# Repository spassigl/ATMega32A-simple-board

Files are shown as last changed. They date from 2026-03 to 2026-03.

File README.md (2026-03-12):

# ATMega32A demo board
An ATMega32A demo board with exposed GPIO pins, LEDs, tactile switches and a buzzer

## The project
This is a simple ATMega32A board that I used to test some ideas for a bigger project. 
It's a small factor pcb - 84x44mm - with the following features:
- ATMega32A clocked at 16MHz
- USB-C conneector for power and, with a booloader like urboot, for firmware updates and serial communication. 
- ISP 6-pin connector to flash bootloader or firmware (in case you don't want to use a booloader like urboot or optiboot)
- Power OR-ing - can have both ISP and USB connected
- All the unused GPIO pins are exposed via connectors on the side of the board
- Includes a buzzer, two LEDs, two tactile buttons
- Footprints are optimized for JLCPCB and "Basic" or "Preferred Extended" parts, to lower assembly costs

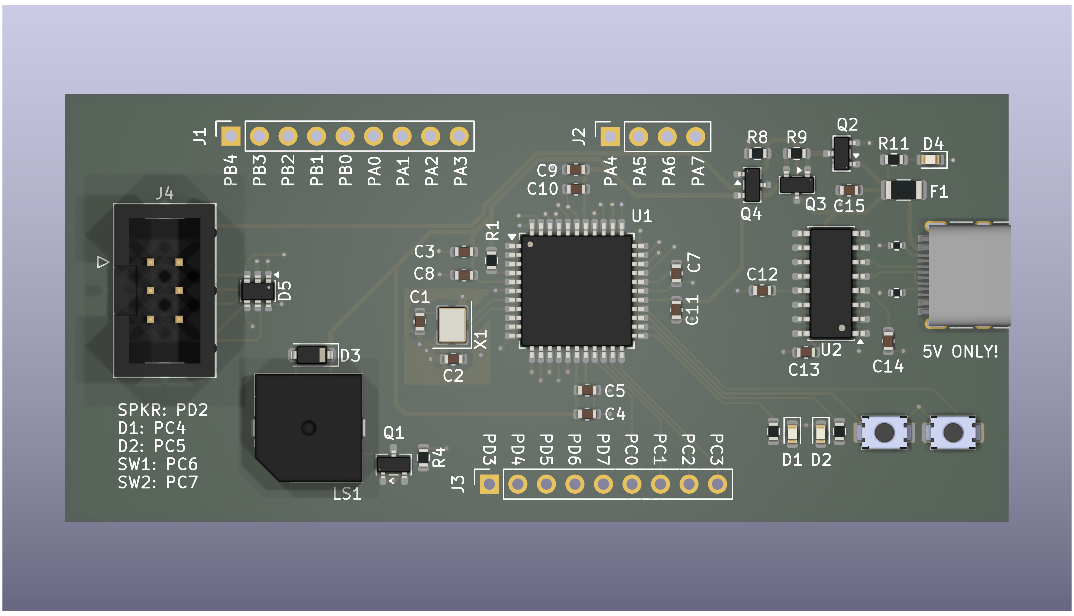
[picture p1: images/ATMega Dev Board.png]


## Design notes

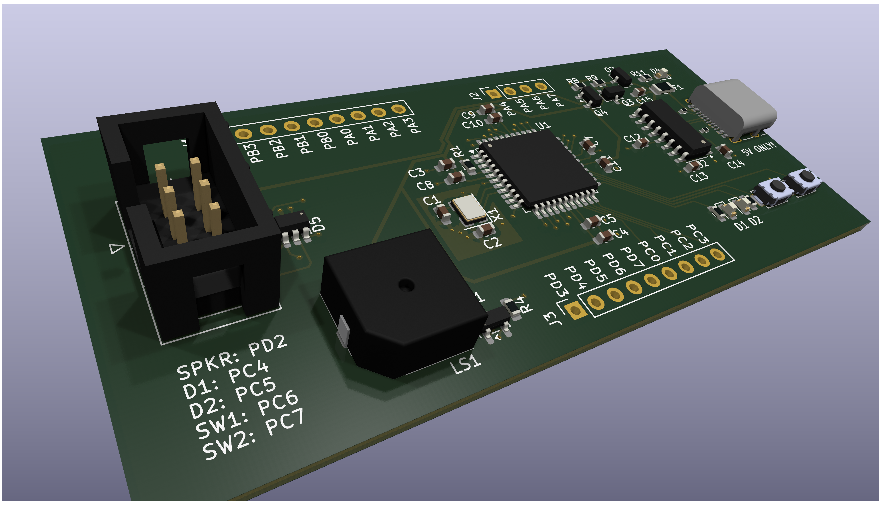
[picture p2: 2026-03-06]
images/ATMega Dev Board 3.png

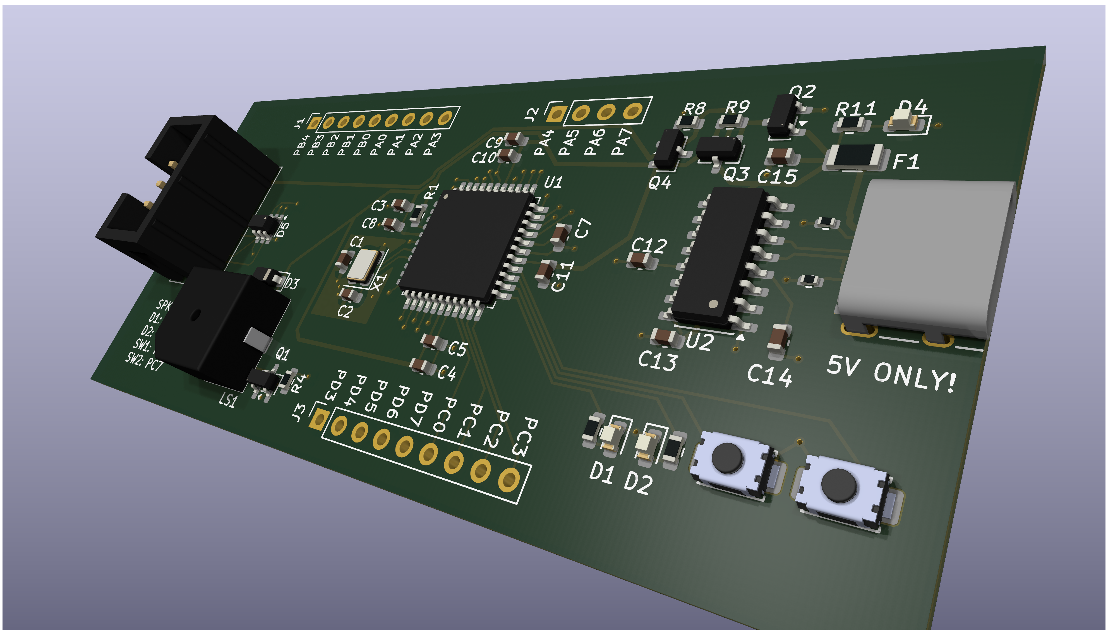
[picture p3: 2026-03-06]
images/ATMega Dev Board 2.png

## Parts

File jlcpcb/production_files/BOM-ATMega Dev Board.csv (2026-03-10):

Comment | Designator | Footprint | LCSC | Quantity
0.1u | C10,C11,C12,C13,C14,C5,C7,C8 | C_0603_1608Metric | C14663 | 8
10k | R1 | R_0603_1608Metric | C25804 | 1
16MHz | X1 | Crystal_SMD_3225-4Pin_3.2x2.5mm | C13738 | 1
1N4001 | D3 | D_SOD-123 | C7462829 | 1
1k | R4 | R_0603_1608Metric | C21190 | 1
1u | C15 | C_0603_1608Metric | C15849 | 1
220 | R11,R2,R3 | R_0603_1608Metric | C22962 | 3
22p | C1,C2 | C_0603_1608Metric | C1653 | 2
2N7002 | Q2 | SOT-23 | C8545 | 1
330k | R8,R9 | R_0603_1608Metric | C23137 | 2
4.7u | C3,C4,C9 | C_0603_1608Metric | C19666 | 3
500mA/24V | F1 | Fuse_1206_3216Metric | C70077 | 1
5k1 | R5,R6 | R_0402_1005Metric | C25905 | 2
ATmega32A-A | U1 | TQFP-44_10x10mm_P0.8mm | C5659 | 1
CH340C | U2 | SOIC-16_3.9x9.9mm_P1.27mm | C84681 | 1
HL6042 | Q3,Q4 | Q_SOT-23 | C28646264 | 2
LED | D1,D2,D4 | LED_0603_1608Metric | C2286 | 3
S8050 | Q1 | SOT-23 | C2146 | 1
SPI header | J4 | IDC-Header_2x03_P2.54mm_Vertical | C492441 | 1
SRV05 | D5 | SOT-23-6 | C85364 | 1
SW_SPST | SW1,SW2 | Switch_TS-1088-AR02016 | C720477 | 2
Speaker | LS1 | Buzzer_MLT-9650 | C96127 | 1
USB-C_31-M-12 | J5 | USB_C_Receptacle_HRO_TYPE-C-31-M-12 | C165948 | 1
USBLC6-2P6 | U3 | SOT-666 | C15999 | 1

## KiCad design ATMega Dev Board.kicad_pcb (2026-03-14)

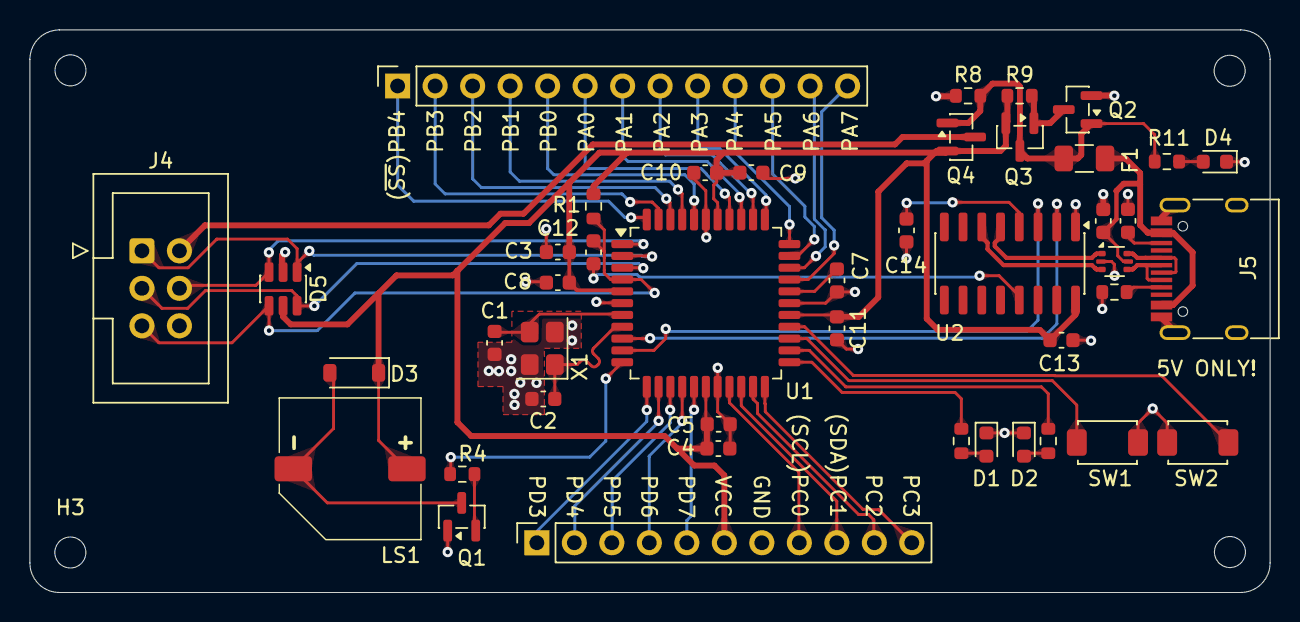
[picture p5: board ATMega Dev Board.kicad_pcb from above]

Board: 4 copper layers, 84.0 x 38.1 mm, 48 parts (0 on the bottom side), 55 nets.

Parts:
C1, C2: 22p; C_0603_1608Metric
C3, C4, C9: 4.7u; C_0603_1608Metric
C5, C6, C7, C8, C10, C11, C12, C13, C14: 0.1u; C_0603_1608Metric
D1, D2, D4: LED; LED_0603_1608Metric
D3: 1N4001; D_SOD-123
D5: SRV05; SOT-23-6
F1: 1A; Fuse_1206_3216Metric
H1, H2, H3, H4: MountingHole; MountingHole_2.1mm
J1: Conn_01x13; PinSocket_1x13_P2.54mm_Vertical
J2: Conn_01x09; PinSocket_1x11_P2.54mm_Vertical
J4: SPI header; IDC-Header_2x03_P2.54mm_Vertical
J5: USB-C_31-M-12; USB_C_Receptacle_HRO_TYPE-C-31-M-12
LS1: Speaker; Buzzer_MLT-9650
Q1: S8050; SOT-23
Q2: 2N7002; SOT-23
Q3, Q4: HL6042; SOT-23
R1: 10k; R_0603_1608Metric
R2, R3: 220; R_0603_1608Metric
R4: 1k; R_0603_1608Metric
R5: 5k1; R_0603_1608Metric
R6: 5k1; C_0603_1608Metric
R8, R9: 330k; R_0603_1608Metric
R11: 510; R_0603_1608Metric
SW1, SW2: SW_SPST; Switch_TS-1088-AR02016
U1: ATmega32A-A; TQFP-44_10x10mm_P0.8mm
U2: CH340C; SOIC-16_3.9x9.9mm_P1.27mm
U3: USBLC6-2P6; SOT-666
X1: 16MHz; Crystal_SMD_3225-4Pin_3.2x2.5mm

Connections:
/LED1: R2.1, U1.23 ((TDO)PC4)
/LED2: R3.1, U1.24 ((TDI)PC5)
/MISO: D5.1 (IO1), J4.1 (MISO), U1.2 ((MISO)PB6)
/MOSI: D5.3 (IO2), J4.4 (MOSI), U1.1 ((MOSI)PB5)
/PA0: J1.6, U1.37 ((ADC0)PA0)
/PA1: J1.7, U1.36 ((ADC1)PA1)
/PA2: J1.8, U1.35 ((ADC2)PA2)
/PA3: J1.9, U1.34 ((ADC3)PA3)
/PA4: J1.10, U1.33 ((ADC4)PA4)
/PA5: J1.11, U1.32 ((ADC5)PA5)
/PA6: J1.12, U1.31 ((ADC6)PA6)
/PA7: J1.13, U1.30 ((ADC7)PA7)
/PB0: J1.5, U1.40 ((XCK/T0)PB0)
/PB1: J1.4, U1.41 ((T1)PB1)
/PB2: J1.3, U1.42 ((AIN0/INT2)PB2)
/PB3: J1.2, U1.43 ((AIN1/OC0)PB3)
/PB4: J1.1, U1.44 ((~SS)PB4)
/PC0: J2.8, U1.19 ((SCL)PC0)
/PC1: J2.9, U1.20 ((SDA)PC1)
/PC2: J2.10, U1.21 ((TCK)PC2)
/PC3: J2.11, U1.22 ((TMS)PC3)
/PD3: J2.1, U1.12 ((INT1)PD3)
/PD4: J2.2, U1.13 ((OC1B)PD4)
/PD5: J2.3, U1.14 ((OC1A)PD5)
/PD6: J2.4, U1.15 ((ICP1)PD6)
/PD7: J2.5, U1.16 ((OC2)PD7)
/RST: C12.1, D5.4 (IO3), J4.5 (~RST), R1.2, U1.4 (~RESET)
/SCK: D5.6 (IO4), J4.3 (SCK), U1.3 ((SCK)PB7)
/SPKR: R4.1, U1.11 ((INT0)PD2)
/SW1: SW1.1 (A), U1.25 ((TOSC1)PC6)
/SW2: SW2.1 (A), U1.26 ((TOSC2)PC7)
/UD+: U2.5 (UD+), U3.1 (I/O1)
/UD-: U2.6 (UD-), U3.3 (I/O2)
/UD_N: J5.A7 (D-), J5.B7 (D-), U3.4 (I/O2)
/UD_P: J5.A6 (D+), J5.B6 (D+), U3.6 (I/O1)
/URXD: U1.10 ((TXD)PD1), U2.3 (RXD)
/UTXD: U1.9 ((RXD)PD0), U2.2 (TXD)
GND: C1.2, C2.2, C3.1, C4.1, C5.2, C6.2, C7.1, C8.2, C9.1, C10.2, C11.2, C13.1, C14.1, D1.1 (K), D2.1 (K), D4.1 (K), D5.2 (VN), J2.7, J4.6 (GND), J5.A1 (GND), J5.A12 (GND), J5.B1 (GND), J5.B12 (GND), J5.S1 (SHIELD), Q1.1 (E), Q2.2 (S), R5.1, R6.1, R8.1, SW1.2 (B), SW2.2 (B), U1.6 (GND), U1.18 (GND), U1.28 (GND), U1.39 (GND), U2.1 (GND), U3.2 (GND), X1.2 (G), X1.4 (G)
unnamed: D1.2 (A), R2.2
unnamed: D2.2 (A), R3.2
unnamed: D3.2 (A), LS1.2, Q1.3 (C)
unnamed: D4.2 (A), R11.2
unnamed: J5.A5 (CC1), R5.2
unnamed: J5.B5 (CC2), R6.2
unnamed: Q1.2 (B), R4.2
unnamed: Q2.3 (D), Q3.1 (G), R9.2
unnamed: C7.2, U1.29 (AREF)
unnamed: C2.1, U1.8 (XTAL1), X1.1
unnamed: C1.1, U1.7 (XTAL2), X1.3
unnamed: C14.2, U2.4 (V3)
unnamed: C12.2, U2.13 (~DTR)
VBUS: C6.1, F1.2, J5.A4 (VBUS), J5.A9 (VBUS), J5.B4 (VBUS), J5.B9 (VBUS), U3.5 (VBUS)
VCC: C3.2, C4.2, C5.1, C8.1, C9.2, C10.1, C11.1, C13.2, D3.1 (K), D5.5 (VP), J2.6, LS1.1, Q3.2 (S), Q4.2 (S), R1.1, R9.1, U1.5 (VCC), U1.17 (VCC), U1.27 (AVCC), U1.38 (VCC), U2.16 (VCC)
VSPI: J4.2 (VCC), Q4.3 (D)
VUSB: F1.1, Q2.1 (G), Q3.3 (D), Q4.1 (G), R8.2, R11.1

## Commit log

2026-03-04 Version A
    [ATMega Dev Board.kicad_pcb, ATMega Dev Board.kicad_sch, BOM-ATMega Dev Board.csv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]
2026-03-04 Better traces
    [ATMega Dev Board.kicad_pcb]
2026-03-06 Added power OR-ing
    [ATMega Dev Board.kicad_pcb, ATMega Dev Board.kicad_sch, BOM-ATMega Dev Board.csv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]
2026-03-07 Updated fabrication files
    [BOM-ATMega Dev Board.csv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]
2026-03-08 corrected usb connections
    [ATMega Dev Board.kicad_pcb, ATMega Dev Board.kicad_sch]
2026-03-10 added USB ESD protection
    [ATMega Dev Board.kicad_pcb, ATMega Dev Board.kicad_sch, BOM-ATMega Dev Board.csv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]
2026-03-11 correct UART signalling
    [ATMega Dev Board.kicad_pcb, ATMega Dev Board.kicad_sch]
2026-03-11 tweaked clearances
    [ATMega Dev Board.kicad_pcb]
2026-03-12 added KiCad logo
    [ATMega Dev Board.kicad_pcb]
2026-03-13 new stackup
    [ATMega Dev Board.kicad_pcb]
2026-03-13 added teardrops
    [ATMega Dev Board.kicad_pcb]
2026-03-14 updated constraints and traces
    [ATMega Dev Board.kicad_pcb]
